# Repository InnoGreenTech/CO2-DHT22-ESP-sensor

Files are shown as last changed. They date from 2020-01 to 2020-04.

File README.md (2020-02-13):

CO2-DHT22-ESP-sensor
====================

Description:
------------

This is a MH-Z19B, CO2 sensor, a DHT22, humidity and temperature sensor; connected at a nodemcu with a oled screen.

It have a interface web and an update by http interface. It is possible to connect it in Modbus.

[*You can found more information on my web site on this page*](http://innogreentech.fr/en/connected-objects/measures/62-co2-temperature-and-humidity-sensor)

I share also the drawing, the pcb, and the box designe in this repository.

Picture of current status

Contributing:
-------------

Fork it
Create your feature branch (git checkout -b my-new-feature)
Commit your changes (git commit -am 'Add some feature')
Push to the branch (git push origin my-new-feature)
Create new Pull Request

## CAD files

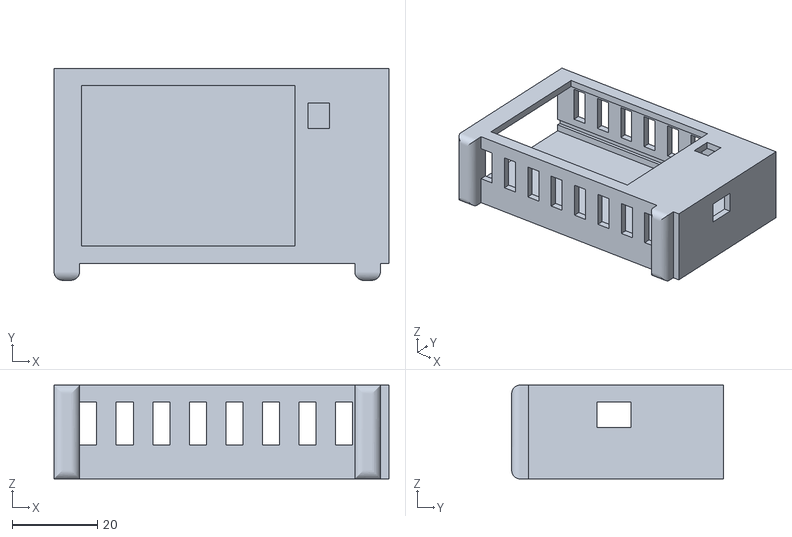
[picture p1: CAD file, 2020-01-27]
Boitier3D/main_body.stl
78.5 x 49.6 x 22.0

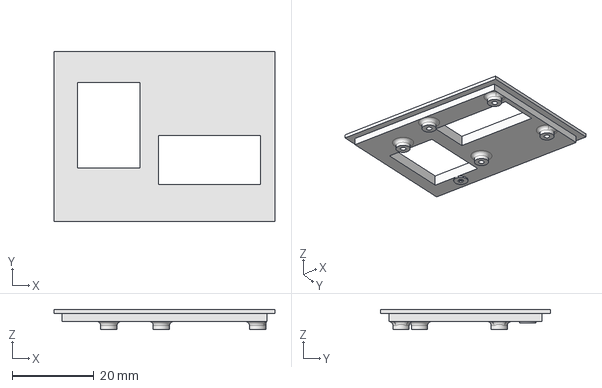
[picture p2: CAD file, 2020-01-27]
Boitier3D/Capteur_CO2_NodeMCU.FCStd
54.0 x 41.5 x 5.00 mm

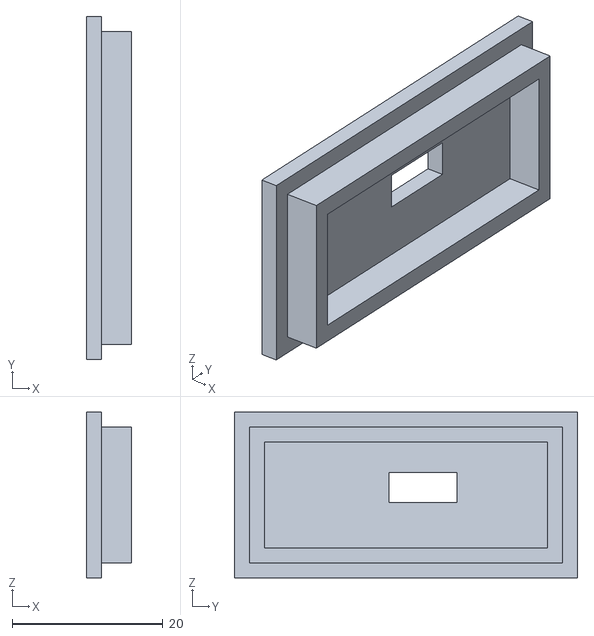
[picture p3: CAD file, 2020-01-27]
Boitier3D/side_close.stl
6.00 x 45.5 x 22.0

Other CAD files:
Boitier3D/cover_probe.stl

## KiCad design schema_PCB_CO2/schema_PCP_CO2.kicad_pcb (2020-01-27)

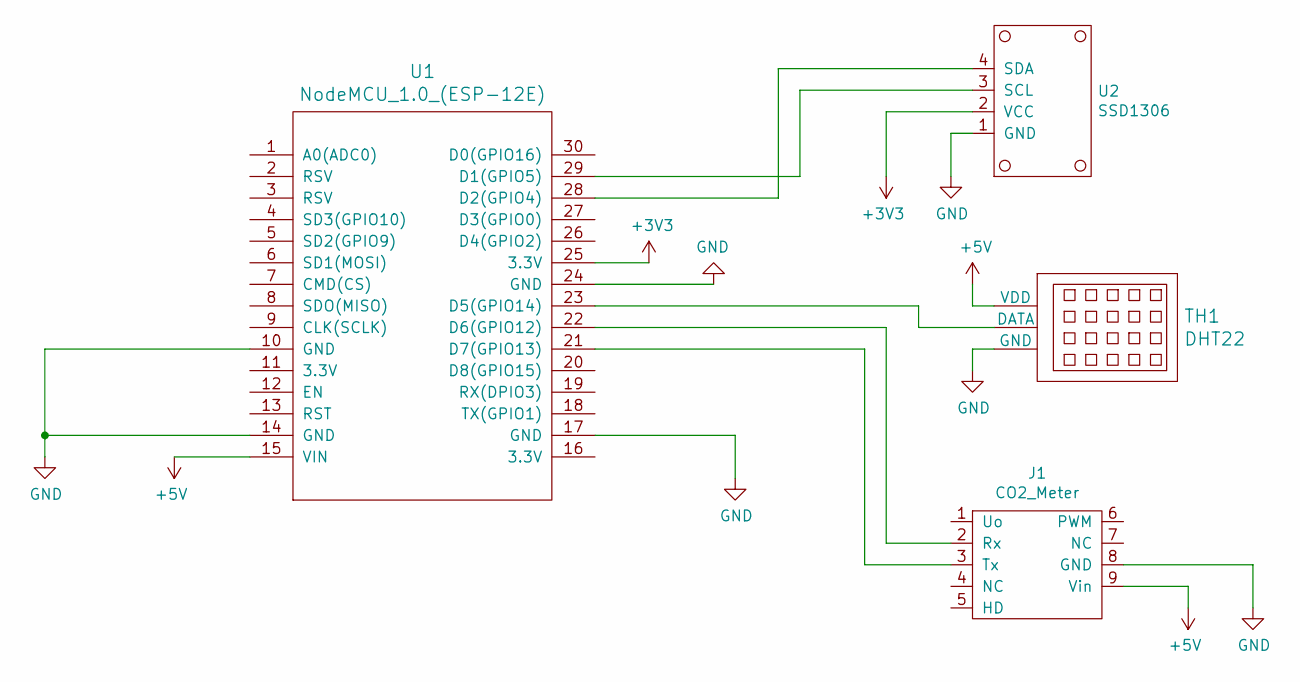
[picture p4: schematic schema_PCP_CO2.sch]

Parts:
J1: CO2_Meter; MHZ19B
TH1: DHT22; DHT22_Temperature_Humidity
U1: NodeMCU_1.0_(ESP-12E); NodeMCU-LoLinV3
U2: SSD1306

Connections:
+3V3: U1.25 (3.3V), U2.2 (VCC)
+5V: J1.9 (Vin), TH1.1 (VDD), U1.15 (VIN)
GND: J1.8 (GND), TH1.3 (GND), U1.10 (GND), U1.14 (GND), U1.17 (GND), U1.24 (GND), U2.1 (GND)
unnamed: J1.2 (Rx), U1.22 (D6(GPIO12))
unnamed: J1.3 (Tx), U1.21 (D7(GPIO13))
unnamed: TH1.2 (DATA), U1.23 (D5(GPIO14))
unnamed: U1.28 (D2(GPIO4)), U2.4 (SDA)
unnamed: U1.29 (D1(GPIO5)), U2.3 (SCL)

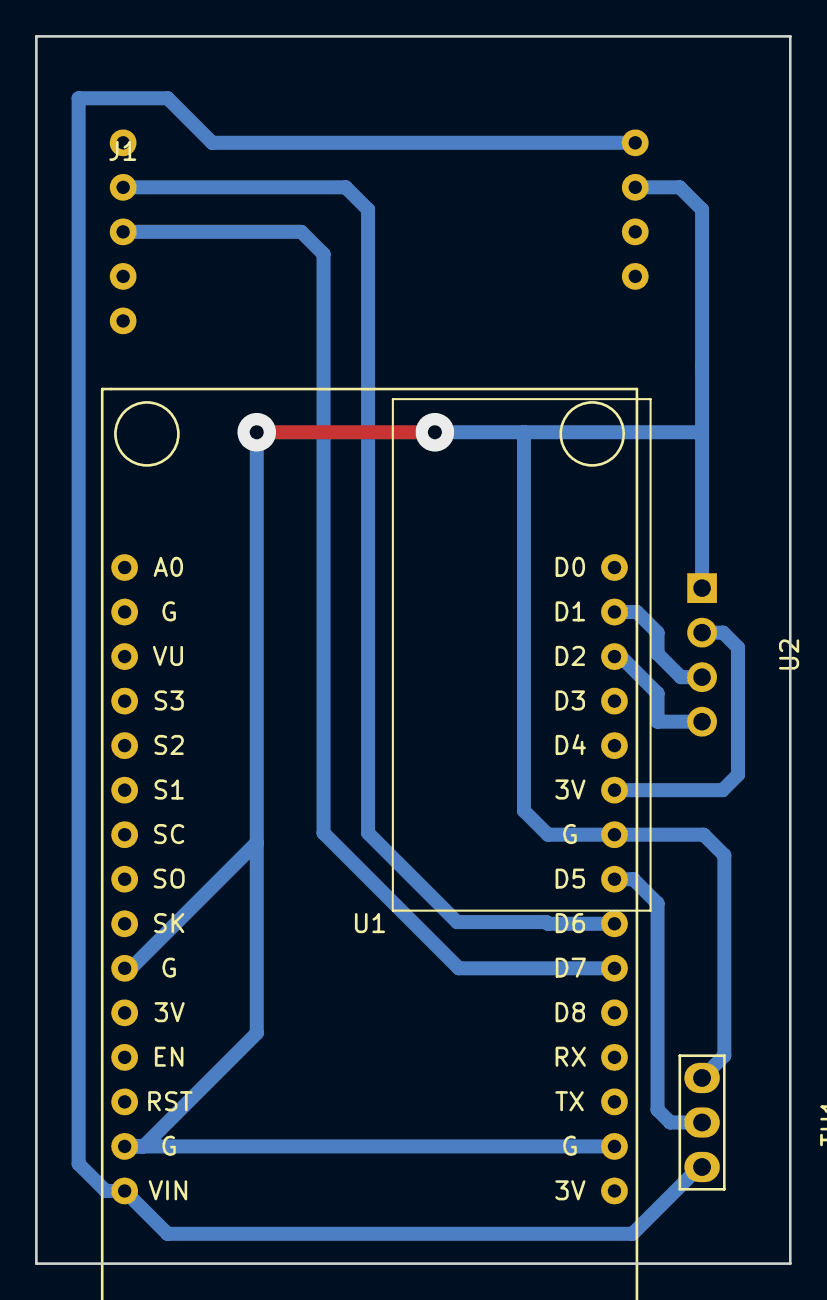
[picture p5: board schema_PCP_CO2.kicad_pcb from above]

Board: 2 copper layers, 43.0 x 70.0 mm, 4 parts (0 on the bottom side), 8 nets.

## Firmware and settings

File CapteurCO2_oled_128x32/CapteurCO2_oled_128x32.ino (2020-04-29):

/* library system*/
#include <SPI.h>
#include <stdio.h>
#include <ArduinoJson.h>
#include <Wire.h>
#include <EEPROM.h>
#include <ESP8266WiFi.h>
#include <wchar.h>
#include <WString.h>
#include <ESP8266HTTPClient.h>
#include <ESP8266WebServer.h>
#include <TimeLib.h>
#include <NtpClientLib.h>
#include <ESP8266mDNS.h>
#include <ESP8266HTTPUpdateServer.h>
#include <DHT.h>

/* use to enable sleep mode */

extern "C" {
#include "user_interface.h"
}

#include <Modbus.h>
#include <ModbusIP_ESP8266.h>

//Modbus Registers Offsets (0-9999)
const int HIGH_WORD = 101;
const int LOW_WORD = 100;
//ModbusIP object
ModbusIP mb;

long ts;

/* configuration eeprom memory */

#define NAME_MODULE     0
#define ADRESS_SERVER   20
#define PORT_SERVER     40
#define PERIOD          44
#define MEM_SSID        46
#define MEM_PASSWORD    76
#define ALARME_EEPROM  100


#define TEMPERATURE_MAX     102    //Temperature maximum
#define TEMPERATURE_MIN     104    //Température minimum
#define TEMPERATURE_OFFSET  106

#define HUMIDITY_MAX     108    //humidity maximum
#define HUMIDITY_MIN     110    //humidity minimum
#define HUMIDITY_OFFSET  112

#define CO2_MAX     116   //humidity maximum
#define CO2_MIN     118    //humidity minimum
#define CO2_OFFSET  120

/* Define variables for the software */

float         temperature;           // in °C
int           humidity;              // in %
int unsigned  co2;                   // ppm
int           period;                // period to sent datas
char          name_module[20];       // name of module
String        ref_module;            // référence du module
String        version_module;        // version of module
char          ip_server[15];         // adress ip of the module
int unsigned  port_server;           // port of server
String        local_mac;             // adress mac of the module
String        local_ip;              // adress ip of module
byte          enableServer = 1 ;     // Use to control if the parameters are good


String        reception;             // To read information
int           code;                  // Variable code pour l'échange d'information
int           consigne='c';
String        ssid = "";
String        password = "";
int           config_mode = 0;
unsigned long delay_reboot;         // delay during the page of connection is open befor reboot

#define DELAY_REBOOT 120000

ESP8266WebServer serverhttp(80);


/* Configuration of screen */

#include <Adafruit_GFX.h>
#include <Adafruit_SSD1306.h>

// SCL GPIO5
// SDA GPIO4
#define OLED_RESET 0
Adafruit_SSD1306 display(OLED_RESET);

#define NUMFLAKES 10
#define XPOS 0
#define YPOS 1
#define DELTAY 2

#if (SSD1306_LCDHEIGHT != 64)
#error("Height incorrect, please fix Adafruit_SSD1306.h!");
#endif

unsigned long refreshScreen;      // taux de rafraîchissement de l'écran
#define REFRESH 8000

/* config update server*/

//const char* host = "esp8266-webupdate";
const char* update_path = "/firmware";
const char* update_username = "inoogreentech";
const char* update_password = "innogreentech";

ESP8266HTTPUpdateServer httpUpdater;


/* DHT temperature and humidity confuguration */

#define DHTPIN D5    // what pin we're connected to
#define DHTTYPE DHT22   // DHT 22,  DHT21, DHT11

DHT dht(DHTPIN, DHTTYPE);

#include <SoftwareSerial.h>
#define MH_Z19_RX D7
#define MH_Z19_TX D6

SoftwareSerial co2Serial(MH_Z19_RX, MH_Z19_TX);


/* alarm */

byte activation_alarmes; // Mot utilisé pour l'activation des alarmes
byte alarmes_actives;     // Drapeau d'une alarme active
int nbenvois = 0;         //nombre d'envoi de mail

#define ALARME_G  0  // Bit d'activation de la surveillance d'alarme
#define ALARME_C  1  // Activate CO2 alarm
#define ALARME_T  2  // Activate Temperature alarm
#define ALARME_H  3  // Activate Humidity alarm

int c_max;    // Set max CO2
int c_min;    // Set min CO2
int c_offset; // offset CO2

int t_max;    // Set max temperature
int t_min;    // Set min temperature
int t_offset; // Set offset temperature

int h_max;    // Set max humidity
int h_min;    // Set min humidity
int h_offset; // Set offset humidity

unsigned long  lastmessage;         // heures d'envoi des derniers relevés
unsigned long  millisecondes;       // Intervalle des relevés en millisecondes
int nb_cycle_lost_wifi=0;  

#define NB_TRYING_CONNECT 4  

void setup()
{
  Serial.begin(115200);
  co2Serial.begin(9600);


 

  /* read memory EEPROM */

  EEPROM.begin(512);

  activation_alarmes = EEPROM.read(ALARME_EEPROM);

  char carac = '1'; // Name of module
  int a = 0;
  while (!(carac == '\0') && a < 20) {
    carac = char (EEPROM.read(NAME_MODULE + a));
    reception += carac;
    a++;
  }
  if (reception == '\0' || a == 20) {
    reception = F("InnoGreenTech");
  }
  int c = reception.length() + 1;                               // longueur de la chaîne de caractéres
  reception.toCharArray(name_module, c);

  reception = "";  // read memory ip adress server
  carac = '1';
  a = 0;
  while (!(carac == '\0') && a < 20) {
    carac = char (EEPROM.read(ADRESS_SERVER + a));
    reception += carac;
    a++;
  }
  if (reception == '\0' || a == 20) {
    reception = F("InnoGreenTech");
    enableServer = 0;
  }
  c = reception.length() + 1;
  reception.toCharArray(ip_server, c);

  byte mem[2];
  for (int a = 0; a < 3; a++) {
    mem[a] = EEPROM.read(PORT_SERVER + a); // load the port server
  }
  port_server = mem[0] | mem[1] << 8;

  for (int a = 0; a < 3; a++) {
    mem[a] = EEPROM.read(PERIOD + a); // load the time period
  }
  period = mem[0] | mem[1] << 8;
  millisecondes = period * 1000;

  for (int a = 0; a < 3; a++) {
    mem[a] = EEPROM.read(TEMPERATURE_MAX + a); // Récupération de la température Max
  }
  t_max = mem[0] | mem[1] << 8;
  for (int a = 0; a < 3; a++) {
    mem[a] = EEPROM.read(TEMPERATURE_MIN + a); // Récupération de la température Minimum
  }
  t_min = mem[0] | mem[1] << 8;
  for (int a = 0; a < 3; a++) {
    mem[a] = EEPROM.read(TEMPERATURE_OFFSET + a);
  }
  t_offset = mem[0] | mem[1] << 8;

  for (int a = 0; a < 3; a++) {
    mem[a] = EEPROM.read(HUMIDITY_MAX + a); // Récupération de la température Max
  }
  t_max = mem[0] | mem[1] << 8;
  for (int a = 0; a < 3; a++) {
    mem[a] = EEPROM.read(HUMIDITY_MIN + a); // Récupération de la température Minimum
  }
  t_min = mem[0] | mem[1] << 8;
  for (int a = 0; a < 3; a++) {
    mem[a] = EEPROM.read(HUMIDITY_OFFSET + a);
  }
  t_offset = mem[0] | mem[1] << 8;

  for (int a = 0; a < 3; a++) {
    mem[a] = EEPROM.read(CO2_MAX + a); // Récupération de la température Max
  }
  t_max = mem[0] | mem[1] << 8;
  for (int a = 0; a < 3; a++) {
    mem[a] = EEPROM.read(CO2_MIN + a); // Récupération de la température Minimum
  }
  t_min = mem[0] | mem[1] << 8;
  for (int a = 0; a < 3; a++) {
    mem[a] = EEPROM.read(CO2_OFFSET + a);
  }
  t_offset = mem[0] | mem[1] << 8;

  carac = '1';
  a = 0;
  while (!(carac == '\0') && a < 100) {
    carac = char (EEPROM.read(MEM_SSID + a));  //récupération du lien d'information
    if (!(carac == '\0')) {
      ssid += carac;
    } a++;
  }
  if (ssid == '\0' || a > 50) {
    ssid = F("");
  }

  carac = '1';
  a = 0;
  while (!(carac == '\0') && a < 100) {
    carac = char (EEPROM.read(MEM_PASSWORD + a));  //récupération du lien d'information
    if (!(carac == '\0')) {
      password += carac;
    } a++;
  }
  if (password == '\0' || a > 50) {
    password = F("");
  }

  /*Connexion wifi*/

  WiFi.mode(WIFI_STA);

  c = ssid.length() + 1;
  char char_ssid[50];
  ssid.toCharArray(char_ssid, c);

  c = password.length() + 1;
  char char_password[50];
  password.toCharArray(char_password, c);

  WiFi.begin(char_ssid, char_password);

  delay(20000);

  if ( WiFi.status() != WL_CONNECTED) // Portail de connexion
  {
    WiFi.disconnect();
    WiFi.mode(WIFI_AP);
    config_mode = 1;
    delay(200);
    WiFi.softAP("InnoGreenTech", "innogreentech");
    serverhttp.on ( "/index.html", handleRoot );    // go to set up wifi page
    delay(100);
    serverhttp.on ("/style.css", cssRoot);     // envoi au fichier de configuration de style
    delay(100);
    serverhttp.begin();
    delay_reboot = millis();

  }

  else

  {

    /* Configuration serial port */

    Serial.begin(115200);
    Serial.println("");
    Serial.print ( "IP address: " ); Serial.println ( WiFi.localIP() );


    /*Configuration de la synchronisation de l'heure */

    NTP.begin("pool.ntp.org", 1, true);  //configuration de la récupération de la date,  Serveur+1 heure, Heure été/hivers
    NTP.setInterval(3600);                // Toute les heures

    delay(2000);


    /*informations du module*/

    local_ip = WiFi.localIP().toString().c_str();
    local_mac = WiFi.macAddress(); //.toString().c_str();
    ref_module = "module_oled";
    version_module = "V1";

    Serial.print(F("référence:")); Serial.println(ref_module);
    Serial.print(F("Version:")); Serial.println(version_module);
    Serial.print(F("Adresse IP:")); Serial.println(local_ip);
    Serial.print(F("Adresse MAC:")); Serial.println(local_mac);

    //dns.begin(WiFi.dnsServerIP());
    Serial.print(F("DNS information:"));Serial.println(WiFi.dnsIP());



    /* Configuration du serveur Web */

    serverhttp.on ( "/index.html", indexRoot );    // Renvoi à la page de index
    delay(100);
    serverhttp.on ( "/", indexRoot );    // Renvoi à la page de index
    delay(100);
    serverhttp.on ( "/add_module.csv", add_module );    // Page for add or modify  module by php server
    delay(100);
    serverhttp.on ( "/config_probe.htlm", config_probe );    // Page for do a configuration of probes by php server
    delay(100);
    serverhttp.on ("/style.css", cssRoot);     // envoi au fichier de configuration de style
    delay(100);
    httpUpdater.setup(&serverhttp, update_path, update_username, update_password);

  }

  /*listen on the server*/

    serverhttp.begin();

  /*Config Modbus IP*/
  
    mb.config("InnoGreenTech", "innogreentech");
    mb.addIreg(HIGH_WORD);
    mb.addIreg(LOW_WORD);

    dht.begin();
  
  /*initialisation of the screen*/

    display.begin(SSD1306_SWITCHCAPVCC, 0x3C);  // initialize with the I2C addr 0x3C 
    display.clearDisplay();
    display.setRotation(180);
    display.display();
}

void loop() {
  /* server control */
  
  serverhttp.handleClient();
  mb.task();

 /* Send data*/
    
 if (millis()>lastmessage+millisecondes and enableServer==1){send_data();} 

  /* read data write it on screen */

  if (millis()> refreshScreen + REFRESH )
      {
        float temp=dht.readTemperature();
        int   hum =dht.readHumidity();
        if(temp<100)
        {temperature = temp-5;}
        if(hum<101)
        {humidity = hum;}

        /* use to test and configure CO2 probeµ*/
        if(Serial.available()>0){consigne=Serial.read();Serial.read();Serial.read();}

        

        if (consigne=='m'){co2 = readCO2();Serial.println("Mesure CO2");consigne='m';}
        else if (consigne=='i'){ini_CO2();Serial.println("Init auto calibaration");consigne='m';}
        else if (consigne=='z'){zero_CO2();Serial.println("Zero calibration"),consigne='m';}
        else if (consigne=='c') {manu_cali();Serial.println("Calibration manuel"),consigne='m';} 
        else{co2 = readCO2();Serial.println("Mesure CO2");consigne='m';}

        /* Refresch display */

        
        display.clearDisplay(); 

        if (hour()<24 && hour()>=6 )
        {
          display.setRotation(90);
          display.setTextSize(1);
          display.setTextColor(BLACK, WHITE);
          display.setTextColor(WHITE);
          display.setCursor(0,0);
          display.println(WiFi.localIP());
          display.println("");
          display.setTextSize(2);
          display.print(temperature);
          display.println(" C");
          display.print(humidity);
          display.println(" %");
          display.print(co2);
          display.println(" ppm");
         } 
        display.display();
        refreshScreen=millis();      
        Serial.print(temperature);
        

       //convert float in Byte

        char* c = (char*)(&temperature);
        
        int low_temperature= c[0] | c[1] <<8;
        int high_temperature= c[2]  | c[3] <<8;

        mb.Ireg(HIGH_WORD, high_temperature);
        mb.Ireg(LOW_WORD, low_temperature);
        
        Serial.println(" C");
        Serial.print(humidity);
        Serial.println(" %");
        Serial.print(co2);
        Serial.println(" ppm"); 
          
    
        
            
      }
  

}

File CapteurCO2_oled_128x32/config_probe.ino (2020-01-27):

void config_probe(){

      String id_probe="";


      if ( serverhttp.hasArg("id_prob") ) 
              {      
              reception=serverhttp.arg("id_prob");
              id_probe=reception.toInt();
              }
      else {return;}         

            if (id_probe=="p1")
            { 
              if ( serverhttp.hasArg("off_set") )
              {
              reception = serverhttp.arg("off_set");
              c_offset=reception.toInt();
              int b=t_offset;
              for (int a=0;a<2;a++){EEPROM.write(TEMPERATURE_OFFSET+a ,b);b=b>>8;}
              } 

            
              if ( serverhttp.hasArg("max") )
              {
              reception = serverhttp.arg("max");
              c_max=reception.toInt();
              int b=c_max;
              for (int a=0;a<2;a++){EEPROM.write(CO2_MAX+a ,b);b=b>>8;}
              }   

              if ( serverhttp.hasArg("min") )
              {
              reception = serverhttp.arg("min");
              t_min=reception.toInt();
              int b=c_min;
              for (int a=0;a<2;a++){EEPROM.write(CO2_MIN+a ,b);b=b>>8;} 
              } 

              if ( serverhttp.hasArg("alarm") )
              {
              reception=serverhttp.arg("alarm");
              if (reception.equals("1")) {bitSet(activation_alarmes, ALARME_C);}  // Active alarm
              else {bitClear(activation_alarmes, ALARME_C);}                       
              EEPROM.write(ALARME_EEPROM, activation_alarmes); 
              }
            }  

      if (id_probe=="p2")
            { 
              if ( serverhttp.hasArg("off_set") )
              {
              reception = serverhttp.arg("off_set");
              t_offset=reception.toInt();
              int b=t_offset;
              for (int a=0;a<2;a++){EEPROM.write(TEMPERATURE_OFFSET+a ,b);b=b>>8;}
              } 

            
              if ( serverhttp.hasArg("max") )
              {
              reception = serverhttp.arg("max");
              t_max=reception.toInt();
              int b=t_max;
              for (int a=0;a<2;a++){EEPROM.write(TEMPERATURE_MAX+a ,b);b=b>>8;}
              }   

              if ( serverhttp.hasArg("min") )
              {
              reception = serverhttp.arg("min");
              t_min=reception.toInt();
              int b=t_min;
              for (int a=0;a<2;a++){EEPROM.write(TEMPERATURE_MIN+a ,b);b=b>>8;} 
              } 

              if ( serverhttp.hasArg("alarm") )
              {
              reception=serverhttp.arg("alarm");
              if (reception.equals("1")) {bitSet(activation_alarmes, ALARME_T);}  // Active alarm
              else {bitClear(activation_alarmes, ALARME_T);}                       
              EEPROM.write(ALARME_EEPROM, activation_alarmes); 
              }
            }    
       if (id_probe=="p3")
            { 
              if ( serverhttp.hasArg("off_set") )
              {
              reception = serverhttp.arg("off_set");
              h_offset=reception.toInt();
              int b=h_offset;
              for (int a=0;a<2;a++){EEPROM.write(HUMIDITY_OFFSET+a ,b);b=b>>8;}
              } 

            
              if ( serverhttp.hasArg("max") )
              {
              reception = serverhttp.arg("max");
              h_max=reception.toInt();
              int b=h_max;
              for (int a=0;a<2;a++){EEPROM.write(HUMIDITY_MAX+a ,b);b=b>>8;}
              }   

              if ( serverhttp.hasArg("min") )
              {
              reception = serverhttp.arg("min");
              h_min=reception.toInt();
              int b=h_min;
              for (int a=0;a<2;a++){EEPROM.write(HUMIDITY_MIN+a ,b);b=b>>8;} 
              } 

              if ( serverhttp.hasArg("alarm") )
              {
              reception=serverhttp.arg("alarm");
              if (reception.equals("1")) {bitSet(activation_alarmes, ALARME_H);}  // Active alarm
              else {bitClear(activation_alarmes, ALARME_H);}                       
              EEPROM.write(ALARME_EEPROM, activation_alarmes); 
              }
            }      
              
           
           EEPROM.commit();
           serverhttp.send ( 200, "text/csv", answer_config_probe() );   // envoi de la page  
        }

String answer_config_probe()
        {
         String page ="Configuration reussie ";
         
         return page;
      }
